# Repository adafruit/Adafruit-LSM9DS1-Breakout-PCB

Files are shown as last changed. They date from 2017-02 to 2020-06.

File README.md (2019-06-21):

## Adafruit LSM9DS1 Breakout PCB

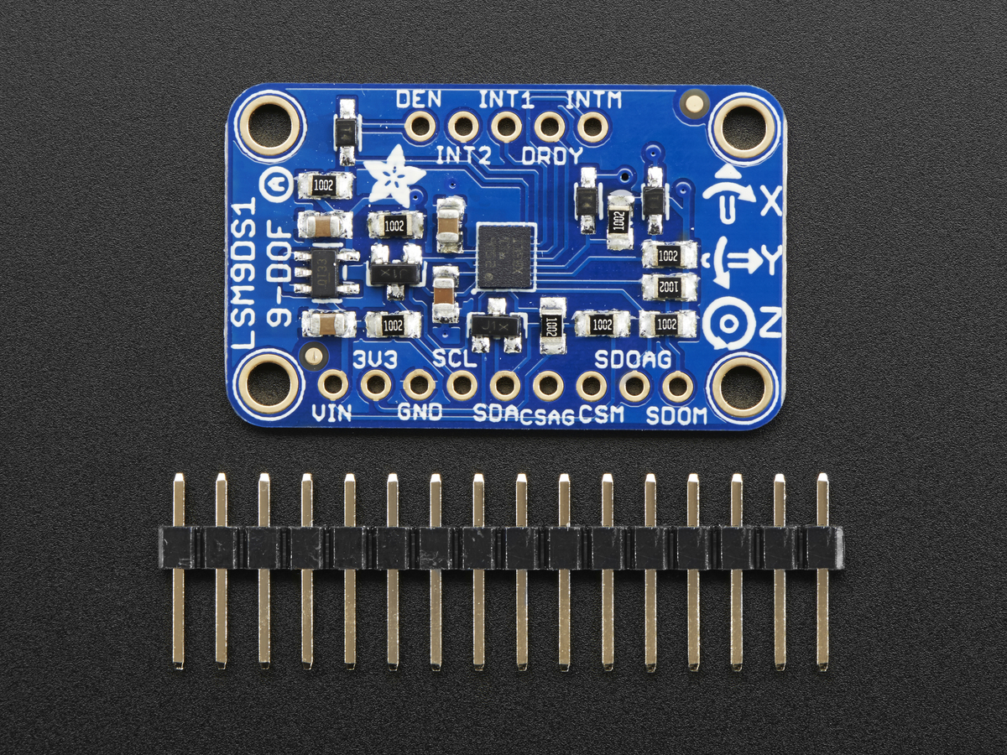
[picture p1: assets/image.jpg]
<a href="http://www.adafruit.com/products/3387"><br/>
Click here to purchase one from the Adafruit shop</a>

PCB files for the Adafruit LSM9DS1 Breakout. Format is EagleCAD schematic and board layout
* https://www.adafruit.com/product/3387

### Description

Add motion, direction and orientation sensing to your Arduino project with this all-in-one 9-DOF sensor. Inside the chip are three sensors, one is a classic 3-axis accelerometer, which can tell you which direction is down towards the Earth (by measuring gravity) or how fast the board is accelerating in 3D space. The other is a 3-axis magnetometer that can sense where the strongest magnetic force is coming from, generally used to detect magnetic north. The third is a 3-axis gyroscope that can measure spin and twist. By combining this data you can REALLY orient yourself.

We've carried the LSM9DS0 from ST for a while, and the LSM9DS1 is their latest offering. We thought this could really make for a great breakout, at a very nice price! Design your own activity or motion tracker with all the data... We spun up a breakout board that has all the extra circuitry you'll want, for use with an Arduino (or other microcontroller).

### License

Adafruit invests time and resources providing this open source design, please support Adafruit and open-source hardware by purchasing products from [Adafruit](https://www.adafruit.com)!

Designed by Limor Fried/Ladyada for Adafruit Industries.

Creative Commons Attribution/Share-Alike, all text above must be included in any redistribution. See license.txt for additional details.

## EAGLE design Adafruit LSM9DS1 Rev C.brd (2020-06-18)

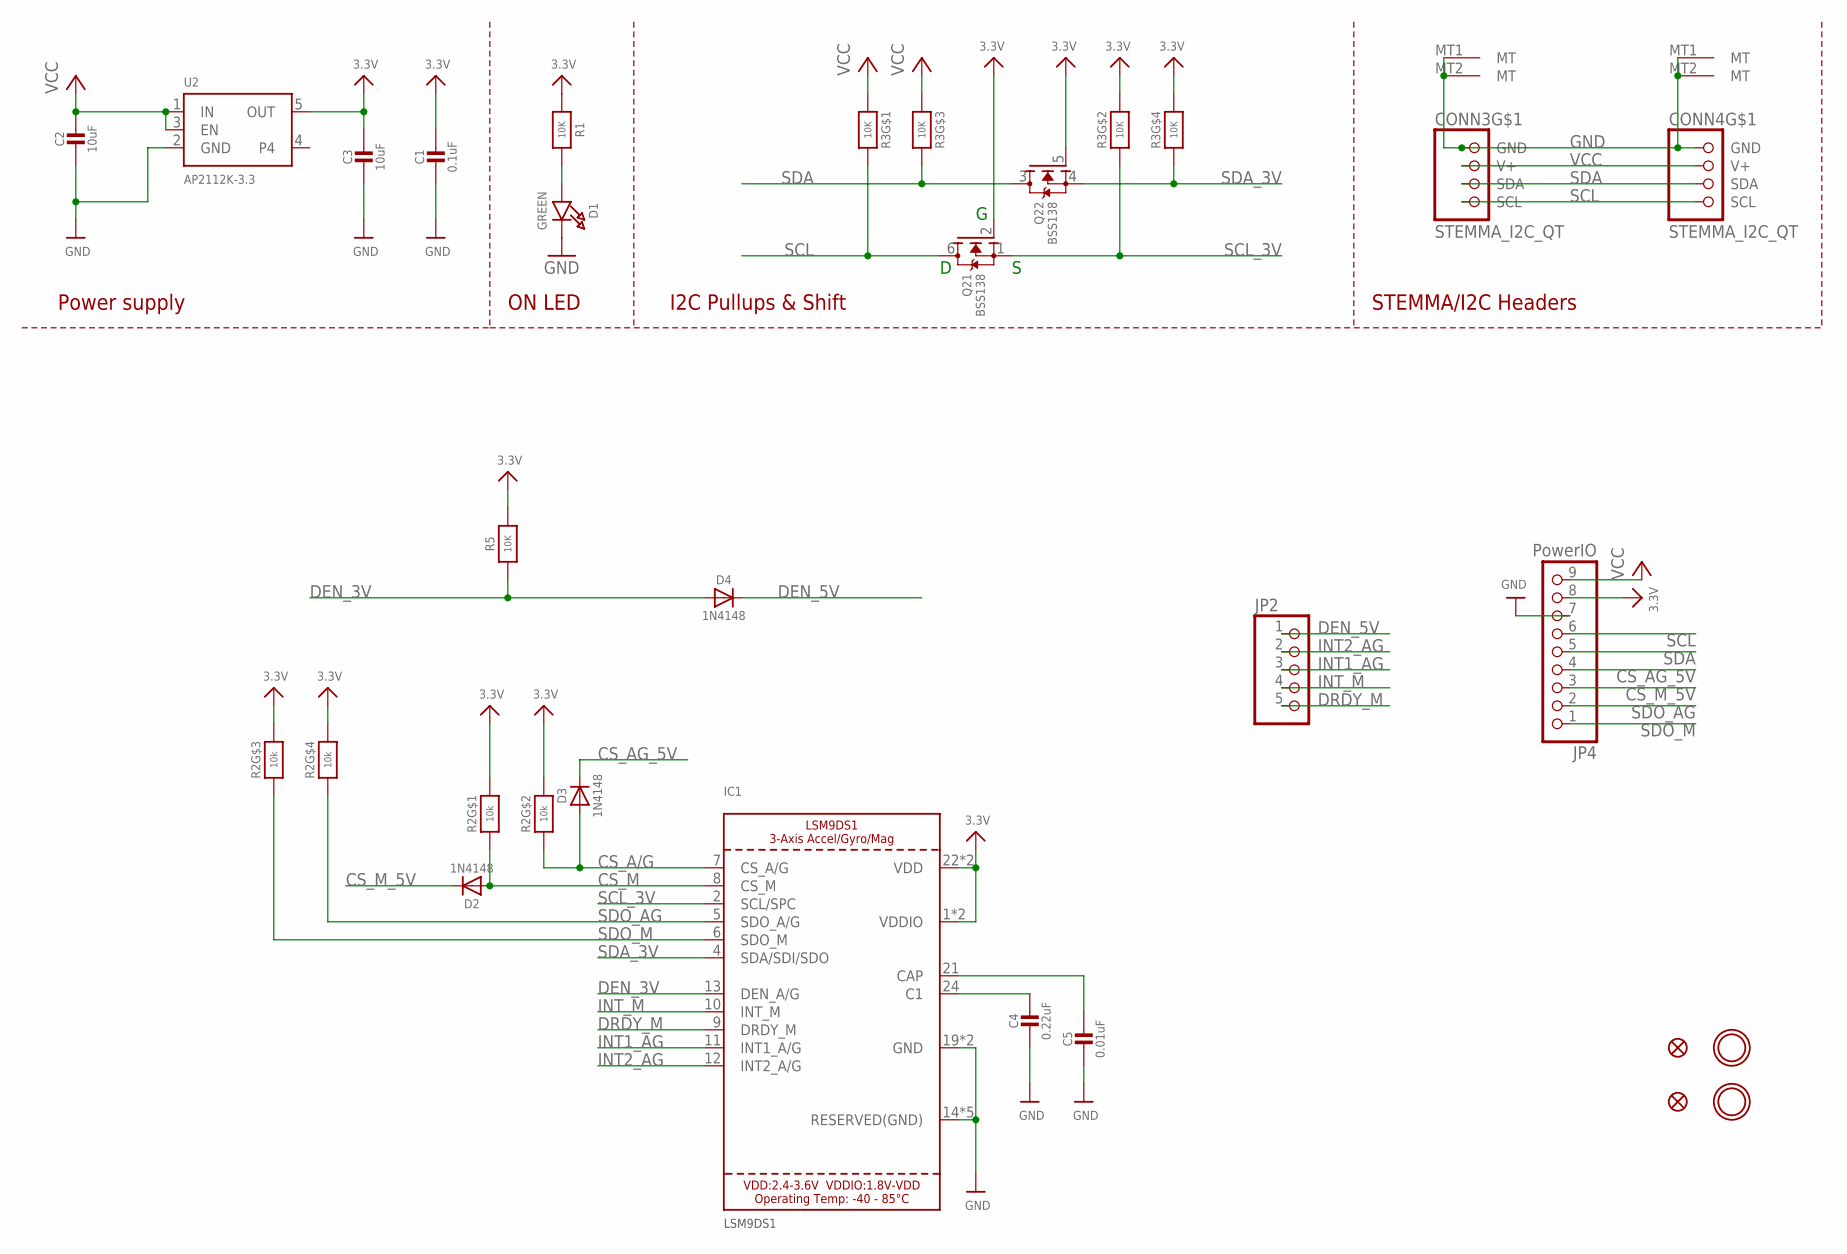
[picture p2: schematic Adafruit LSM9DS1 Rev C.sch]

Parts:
C1: 0.1uF; 0603-NO
C2: 10uF; _0805MP
C3: 10uF; 0805-NO
C4: 0.22uF; 0603-NO
C5: 0.01uF; 0603-NO
CONN3, CONN4: STEMMA_I2C_QT; JST_SH4
D1: GREEN; CHIPLED_0603_NOOUTLINE
D2, D3, D4: 1N4148; SOD-323
FID3, FID4: FIDUCIAL_1MM
IC1: LSM9DS1; LGA24_3.5X3.1MM
JP2: HEADER-1X570MIL; 1X05_ROUND_70
JP4: PowerIO; 1X09_ROUND_70
Q2: BSS138; SOT363
R1, R5: 10K; 0603-NO
R2: 10k; RESPACK_4X0603
R3: 10K; RESPACK_4X0603
U2: AP2112K-3.3; SOT23-5
U$1, U$17: MOUNTINGHOLE2.5; MOUNTINGHOLE_2.5_PLATED

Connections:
3.3V: C1.1, C3.1, IC1.1 (VDDIO), IC1.3 (VDDIO), IC1.22 (VDD), IC1.23 (VDD), JP4.8, Q2.2 (G), Q2.5 (G), R1.1, R2.5 (2), R2.6 (2), R2.7 (2), R2.8 (2), R3.2 (1), R3.4 (1), R5.2, U2.5 (OUT)
C1: C4.1, IC1.24 (C1)
CAP: C5.1, IC1.21 (CAP)
CS_A/G: D3.A, IC1.7 (CS_A/G), R2.2 (1)
CS_AG_5V: D3.C, JP4.4
CS_M: D2.A, IC1.8 (CS_M), R2.1
CS_M_5V: D2.C, JP4.3
DEN_3V: D4.A, IC1.13 (DEN_A/G), R5.1
DEN_5V: D4.C, JP2.1
DRDY_M: IC1.9 (DRDY_M), JP2.5
GND: C1.2, C2.2, C3.2, C4.2, C5.2, CONN3.1 (GND), CONN3.MT1 (MT), CONN3.MT2 (MT), CONN4.1 (GND), CONN4.MT1 (MT), CONN4.MT2 (MT), D1.C, IC1.14 (RESERVED(GND)), IC1.15 (RESERVED(GND)), IC1.16 (RESERVED(GND)), IC1.17 (RESERVED(GND)), IC1.18 (RESERVED(GND)), IC1.19 (GND), IC1.20 (GND), JP4.7, U2.2 (GND)
INT1_AG: IC1.11 (INT1_A/G), JP2.3
INT2_AG: IC1.12 (INT2_A/G), JP2.2
INT_M: IC1.10 (INT_M), JP2.4
unnamed: D1.A, R1.2
SCL: CONN3.4 (SCL), CONN4.4 (SCL), JP4.6, Q2.6 (D), R3.8 (2)
SCL_3V: IC1.2 (SCL/SPC), Q2.1 (S), R3.7 (2)
SDA: CONN3.3 (SDA), CONN4.3 (SDA), JP4.5, Q2.3 (D), R3.6 (2)
SDA_3V: IC1.4 (SDA/SDI/SDO), Q2.4 (S), R3.5 (2)
SDO_AG: IC1.5 (SDO_A/G), JP4.2, R2.4 (1)
SDO_M: IC1.6 (SDO_M), JP4.1, R2.3 (1)
VCC: C2.1, CONN3.2 (V+), CONN4.2 (V+), JP4.9, R3.1, R3.3 (1), U2.1 (IN), U2.3 (EN)

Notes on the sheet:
I2C Pullups & Shift
STEMMA/I2C Headers
ON LED
Power supply

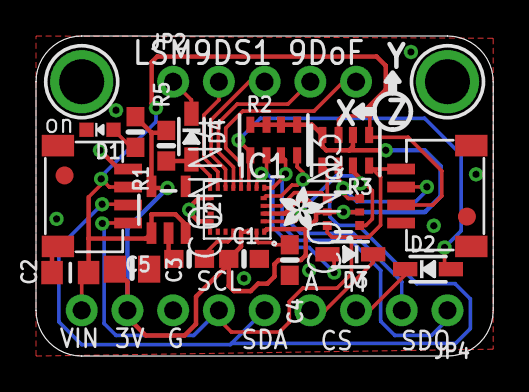
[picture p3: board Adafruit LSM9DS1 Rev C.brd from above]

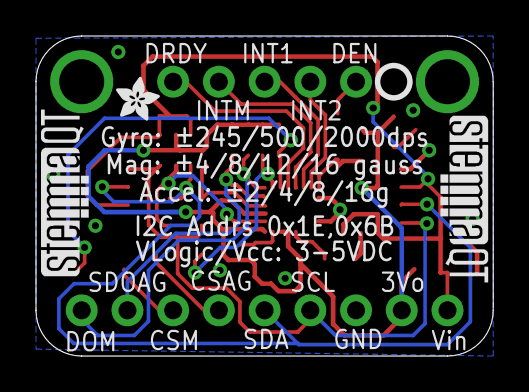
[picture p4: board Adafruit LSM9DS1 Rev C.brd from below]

Board: 2 copper layers, 25.4 x 17.8 mm, 29 parts (4 on the bottom side), 22 nets.

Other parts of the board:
U$10, U$16: ADAFRUIT_2.5MM
U$25: PCBFEAT-REV-040
U$30, U$31: STEMMAQT

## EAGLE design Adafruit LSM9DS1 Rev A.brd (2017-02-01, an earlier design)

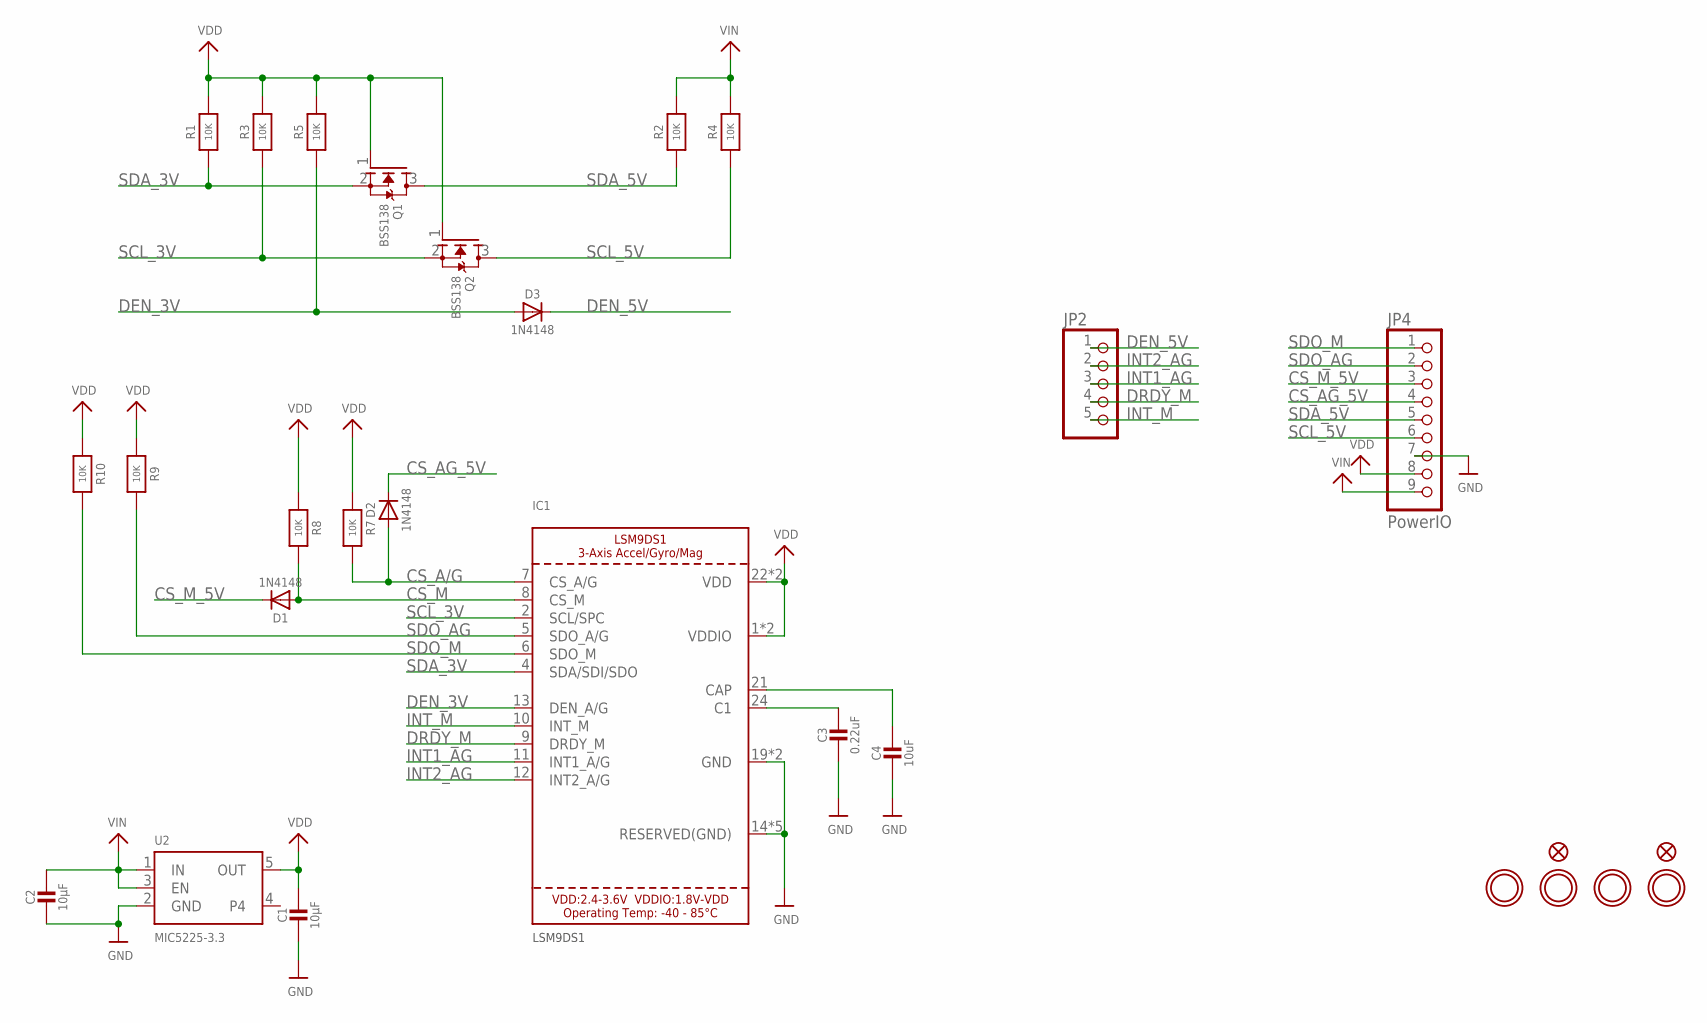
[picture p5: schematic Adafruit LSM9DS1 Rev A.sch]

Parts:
C1, C2: 10µF; 0805-NO
C3: 0.22uF; 0805_10MGAP
C4: 10uF; 0805-NO
D1, D2, D3: 1N4148; SOD-323
FID1, FID3: FIDUCIAL""; FIDUCIAL_1MM
IC1: LSM9DS1; LGA24_3.5X3.1MM
JP2: HEADER-1X570MIL; 1X05_ROUND_70
JP4: PowerIO; 1X09_ROUND_70
Q1, Q2: BSS138; SOT23-WIDE
R1, R9: 10K; 0805_10MGAP
R2, R3, R4, R5, R7, R8, R10: 10K; 0805-NO
U2: MIC5225-3.3; SOT23-5
U$4, U$5, U$6, U$7: MOUNTINGHOLE2.5; MOUNTINGHOLE_2.5_PLATED

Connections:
C1: C3.1, IC1.24 (C1)
CAP: C4.1, IC1.21 (CAP)
CS_A/G: D2.A, IC1.7 (CS_A/G), R7.2
CS_AG_5V: D2.C, JP4.4
CS_M: D1.A, IC1.8 (CS_M), R8.2
CS_M_5V: D1.C, JP4.3
DEN_3V: D3.A, IC1.13 (DEN_A/G), R5.1
DEN_5V: D3.C, JP2.1
DRDY_M: IC1.9 (DRDY_M), JP2.4
GND: C1.2, C2.2, C3.2, C4.2, IC1.14 (RESERVED(GND)), IC1.15 (RESERVED(GND)), IC1.16 (RESERVED(GND)), IC1.17 (RESERVED(GND)), IC1.18 (RESERVED(GND)), IC1.19 (GND), IC1.20 (GND), JP4.7, U2.2 (GND)
INT1_AG: IC1.11 (INT1_A/G), JP2.3
INT2_AG: IC1.12 (INT2_A/G), JP2.2
INT_M: IC1.10 (INT_M), JP2.5
SCL_3V: IC1.2 (SCL/SPC), Q2.2 (S), R3.1
SCL_5V: JP4.6, Q2.3 (D), R4.1
SDA_3V: IC1.4 (SDA/SDI/SDO), Q1.2 (S), R1.1
SDA_5V: JP4.5, Q1.3 (D), R2.1
SDO_AG: IC1.5 (SDO_A/G), JP4.2, R9.2
SDO_M: IC1.6 (SDO_M), JP4.1, R10.2
VDD: C1.1, IC1.1 (VDDIO), IC1.3 (VDDIO), IC1.22 (VDD), IC1.23 (VDD), JP4.8, Q1.1 (G), Q2.1 (G), R1.2, R3.2, R5.2, R7.1, R8.1, R9.1, R10.1, U2.5 (OUT)
VIN: C2.1, JP4.9, R2.2, R4.2, U2.1 (IN), U2.3 (EN)

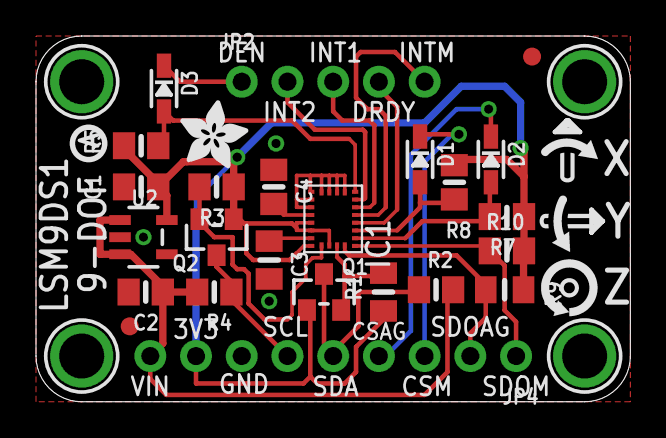
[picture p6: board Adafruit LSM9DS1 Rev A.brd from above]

Board: 2 copper layers, 33.0 x 20.3 mm, 31 parts (0 on the bottom side), 21 nets.

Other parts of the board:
U$14: SYMBOL_GYROXYZ_YREV_10MM
U$20: PCBFEAT-REV-040
U$23: ADAFRUIT_3.5MM

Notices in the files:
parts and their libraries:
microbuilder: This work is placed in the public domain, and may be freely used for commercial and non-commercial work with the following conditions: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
